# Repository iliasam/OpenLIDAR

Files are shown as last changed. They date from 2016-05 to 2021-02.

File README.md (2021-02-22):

# OpenLIDAR
Simple enough scanning laser rangefinder. Based on triangulation method.
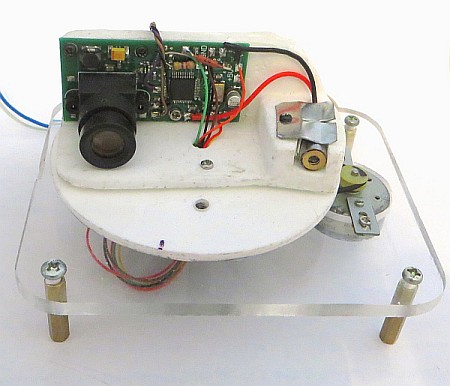
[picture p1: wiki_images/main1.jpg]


Used STM32F303 + ELIS-1024 sensor.

Article in Russian about it: https://geektimes.ru/post/275442/
  
Read wiki for more information.
  
Video - lidar installed at Roomba: https://www.youtube.com/watch?v=4vZgepiK1K4

I have another project of more simple Lidar: https://github.com/iliasam/OpenSimpleLidar  
See also my TOF Lidar project: https://github.com/iliasam/OpenTOFLidar

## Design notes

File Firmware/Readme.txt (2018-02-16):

lidar3_1 - main firmware.

lidar3_image - testing firmware, send image from image sensor to the PC.

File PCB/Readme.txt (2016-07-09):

Important - this PCB was not tested yet.
PCB size - 25x50mm.

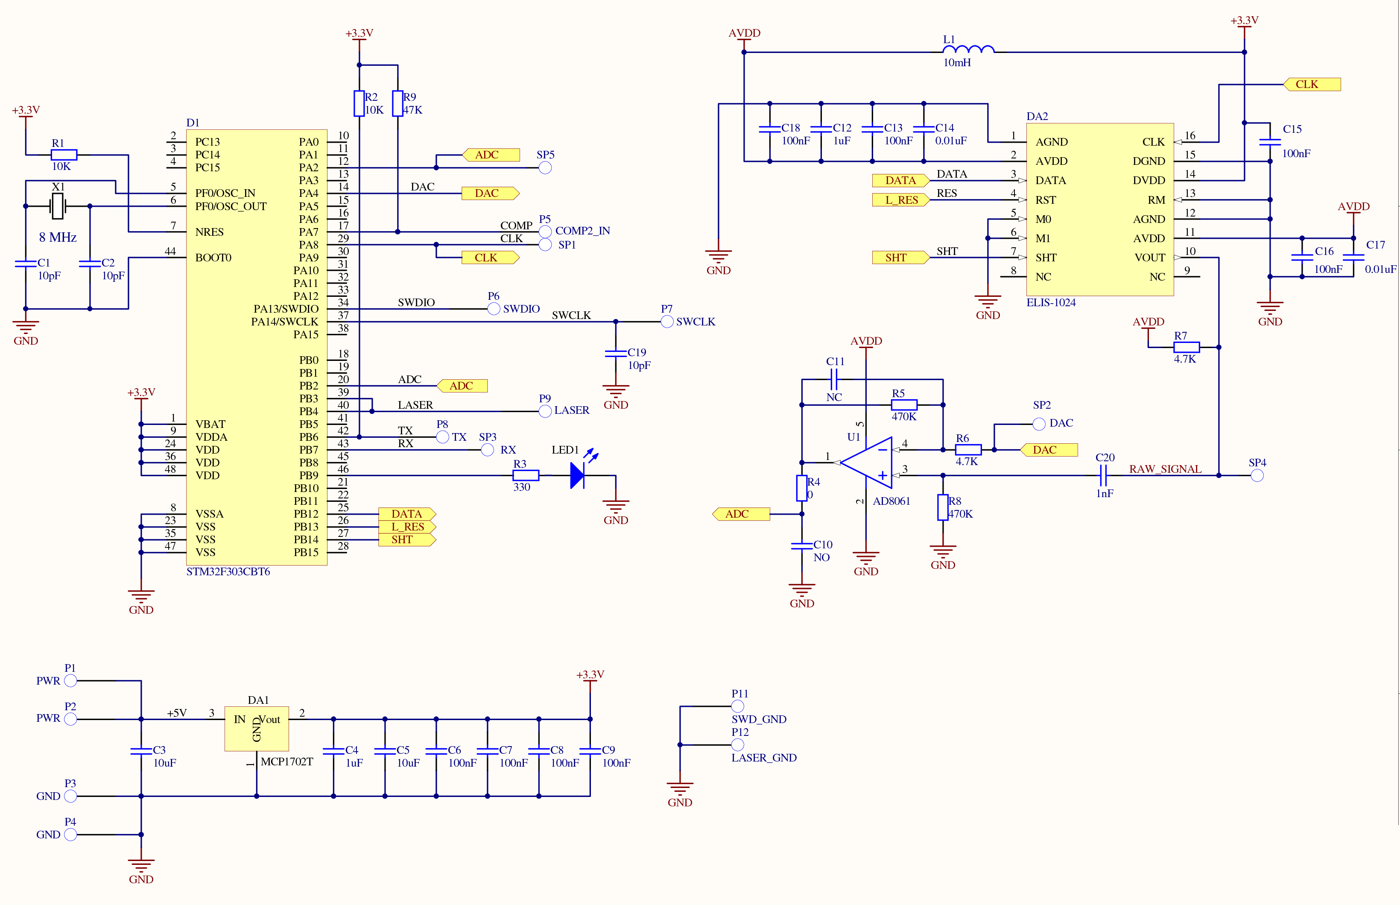
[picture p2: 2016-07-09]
Schematic/schematic_v3_2.png

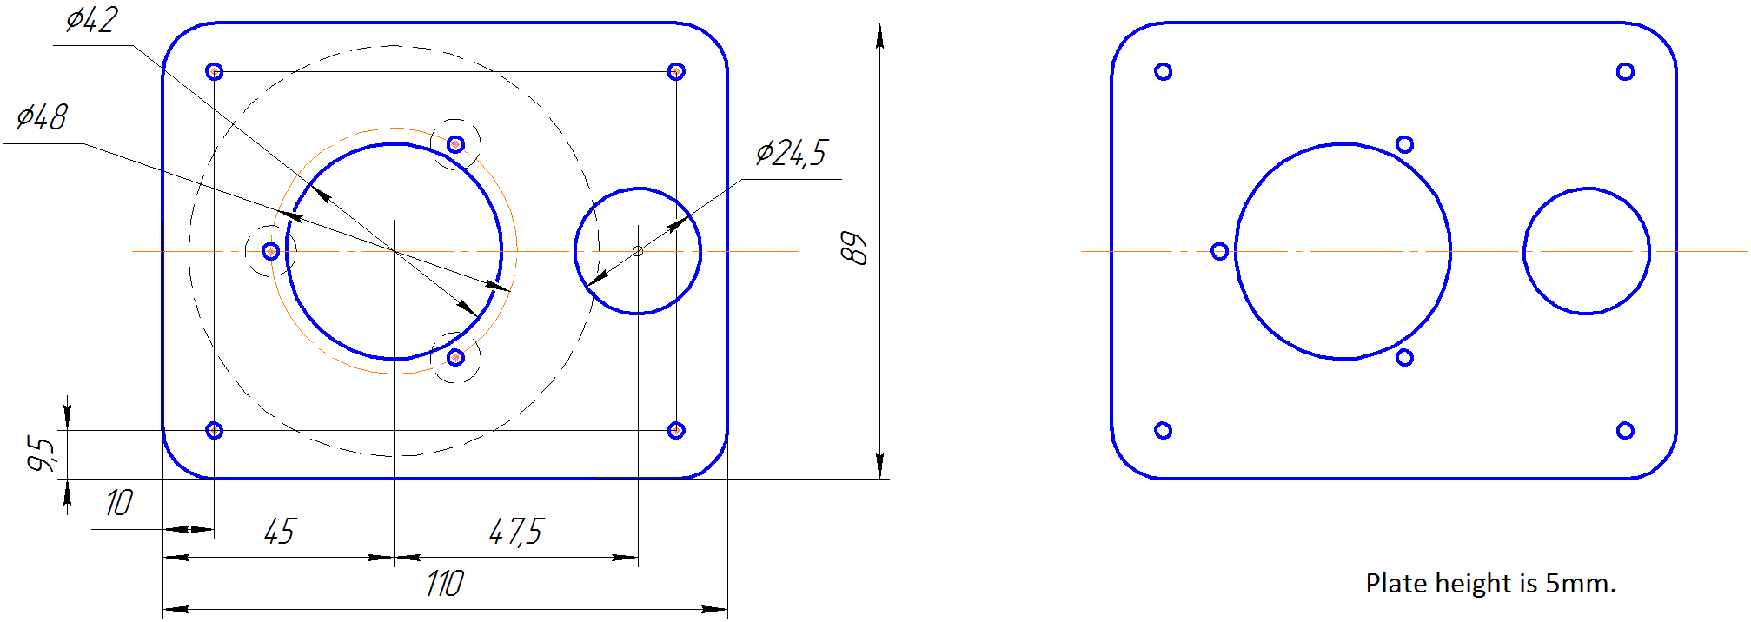
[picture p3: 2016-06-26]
3D_models/base_plate.png

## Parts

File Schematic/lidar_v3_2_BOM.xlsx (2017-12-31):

Designator | Value | Package | Comment
C1 | 10pF | 0603
C2 | 10pF | 0603
C3 | 10uF | Any
C4 | 1uF | CC0805
C5 | 10uF | Any
C6 | 100nF | 0603
C7 | 100nF | 0603
C8 | 100nF | 0603
C9 | 100nF | CC0805
C10 | NO | 0805 | Do not install
C11 | NO | 0805 | Do not install
C12 | 1uF | 0603
C13 | 100nF | 0603
C14 | 0.01uF | 0603
C15 | 100nF | 0603
C16 | 100nF | 0603
C17 | 0.01uF | 0603
C18 | 100nF | 0603
C19 | 10pF | 0603
C20 | 1nF | 0603
D1 | STM32F303CBT6 | LQFP48
DA1 | MCP1702T | MCP1702T
DA2 | ELIS-1024 | LCC16
U1 | AD8061 | SOT-23-5
L1 | 10-20 uH | Any | Inductor
LED1 | LED | 0603
R1 | 10K | 0603
R2 | 10K | 0603
R3 | 330 | 0603
R4 | NO | 0805 | Do not install
R5 | 470K | 0603
R6 | 4.7K | 0603
R7 | 4.7K | 0603
R8 | 470K | 0603
R9 | 47K | 0603
X1 | 8 MHz | SX-6 | Quarzt
P1 | PWR |  | External power
P2 | PWR |  | External power
P3 | GND |  | GND
P4 | GND |  | GND
P5 | COMP2_IN |  | To encoder
P6 | SWDIO |  | SWD
P7 | SWCLK |  | SWD
P8 | TX |  | UART TX
P9 | LASER |  | To laser module +
P11 | SWD_GND |  | SWD
P12 | LASER_GND |  | To laser module -
SP1 | CLK |  | Test point
SP2 | DAC |  | Test point
SP3 | RX |  | Test point
SP4 | RAW |  | Test point
SP5 | CLK |  | Test point

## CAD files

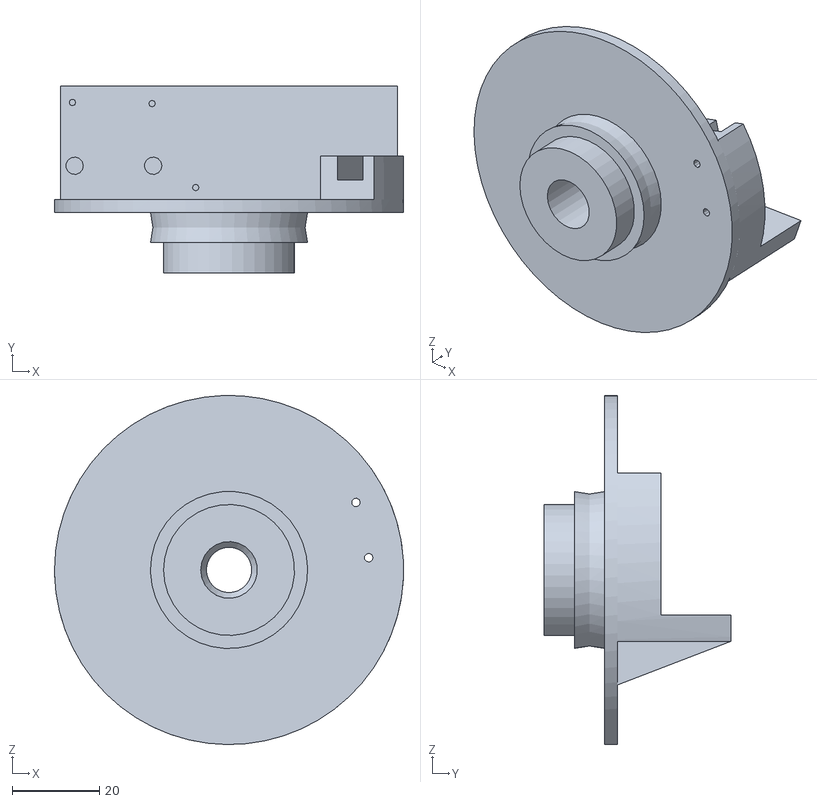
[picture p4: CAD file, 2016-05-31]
3D_models/3d_model_disk2.stl
80.0 x 42.8 x 80.0

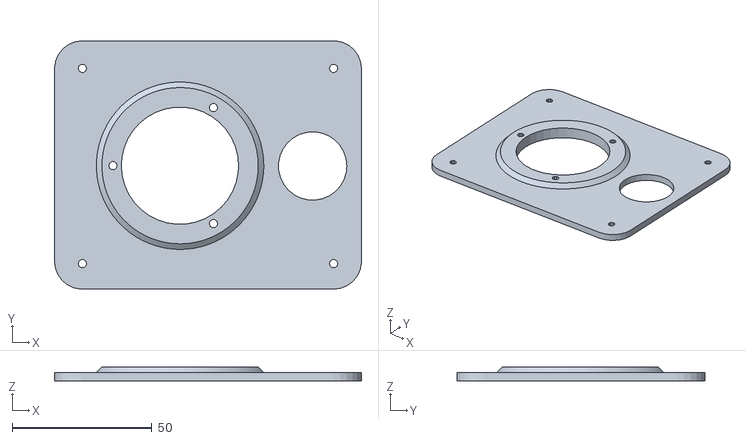
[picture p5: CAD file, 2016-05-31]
3D_models/base_plate.stl
110.0 x 89.0 x 5.00

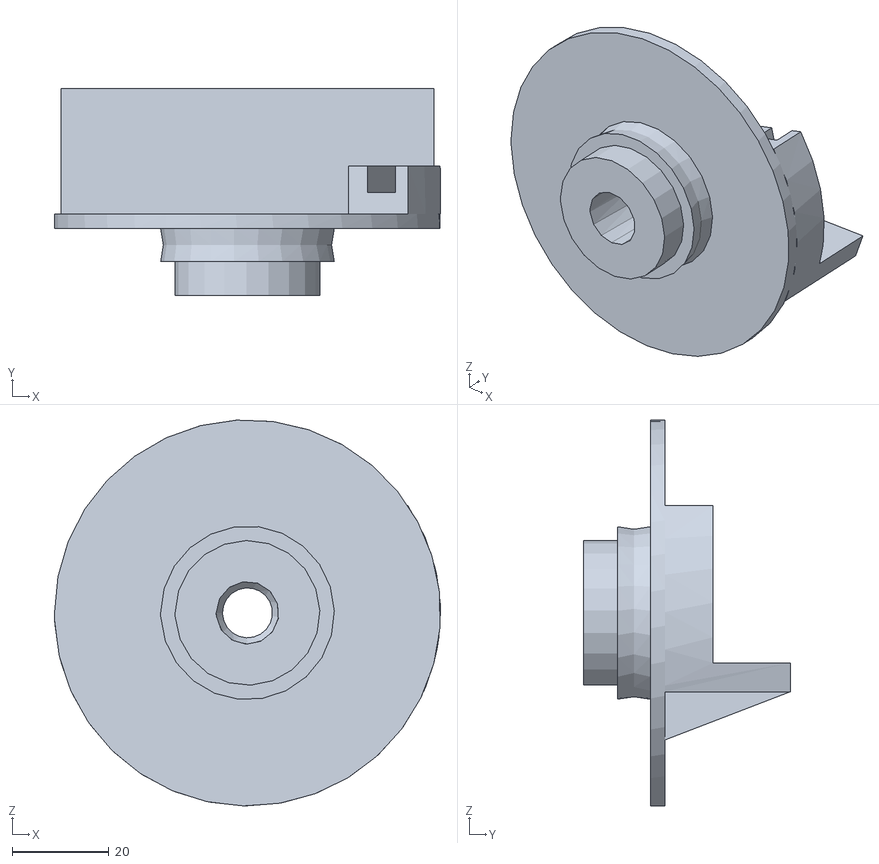
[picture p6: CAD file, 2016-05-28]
3D_models/3d_model_disk.stl
80.0 x 42.8 x 79.9

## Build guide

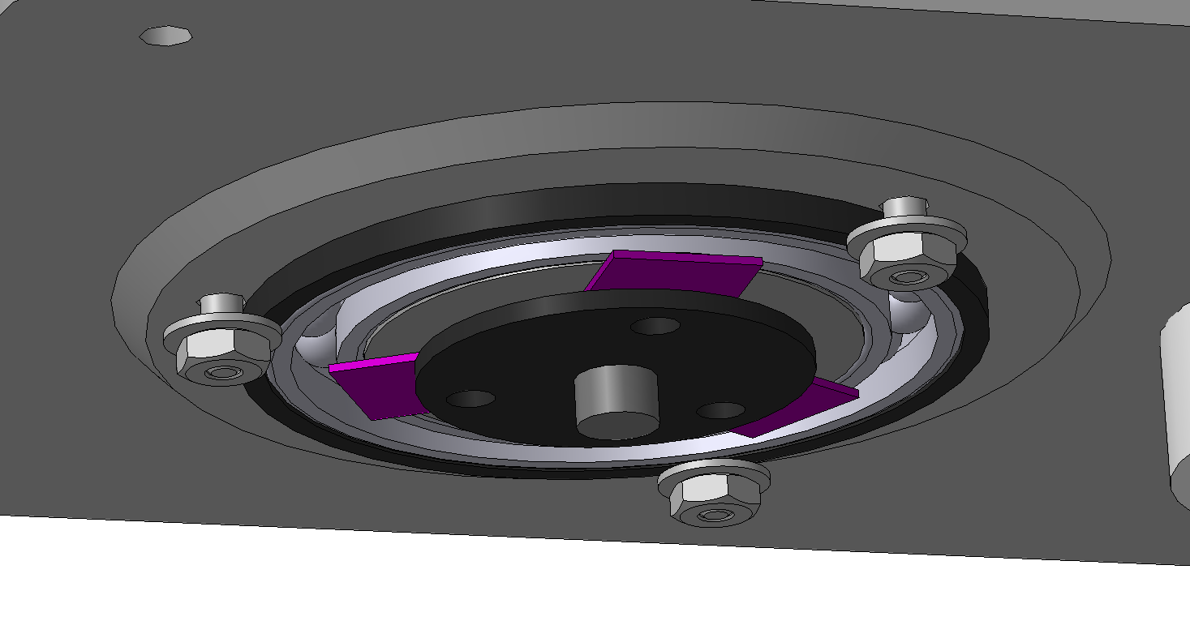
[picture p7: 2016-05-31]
3D_models/build2J.png

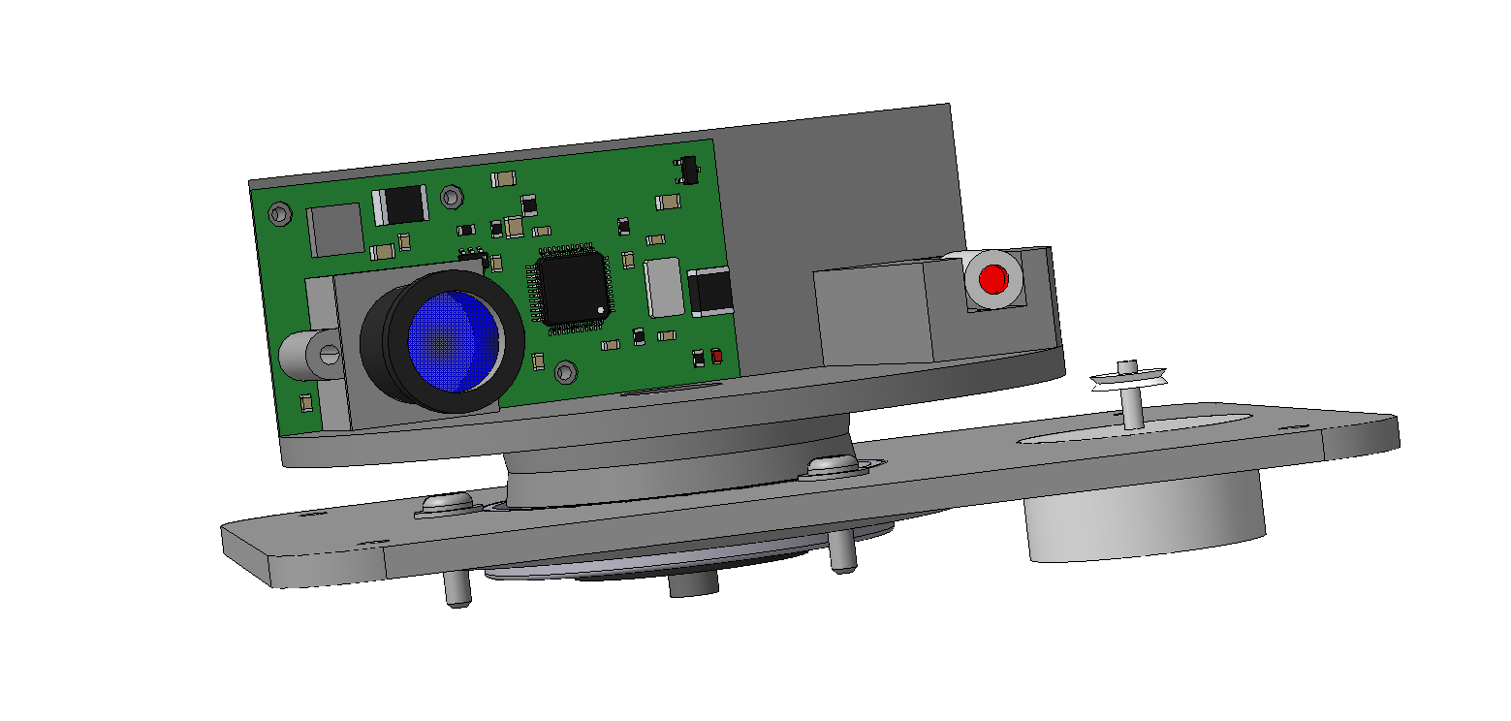
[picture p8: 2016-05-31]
3D_models/build2b.png

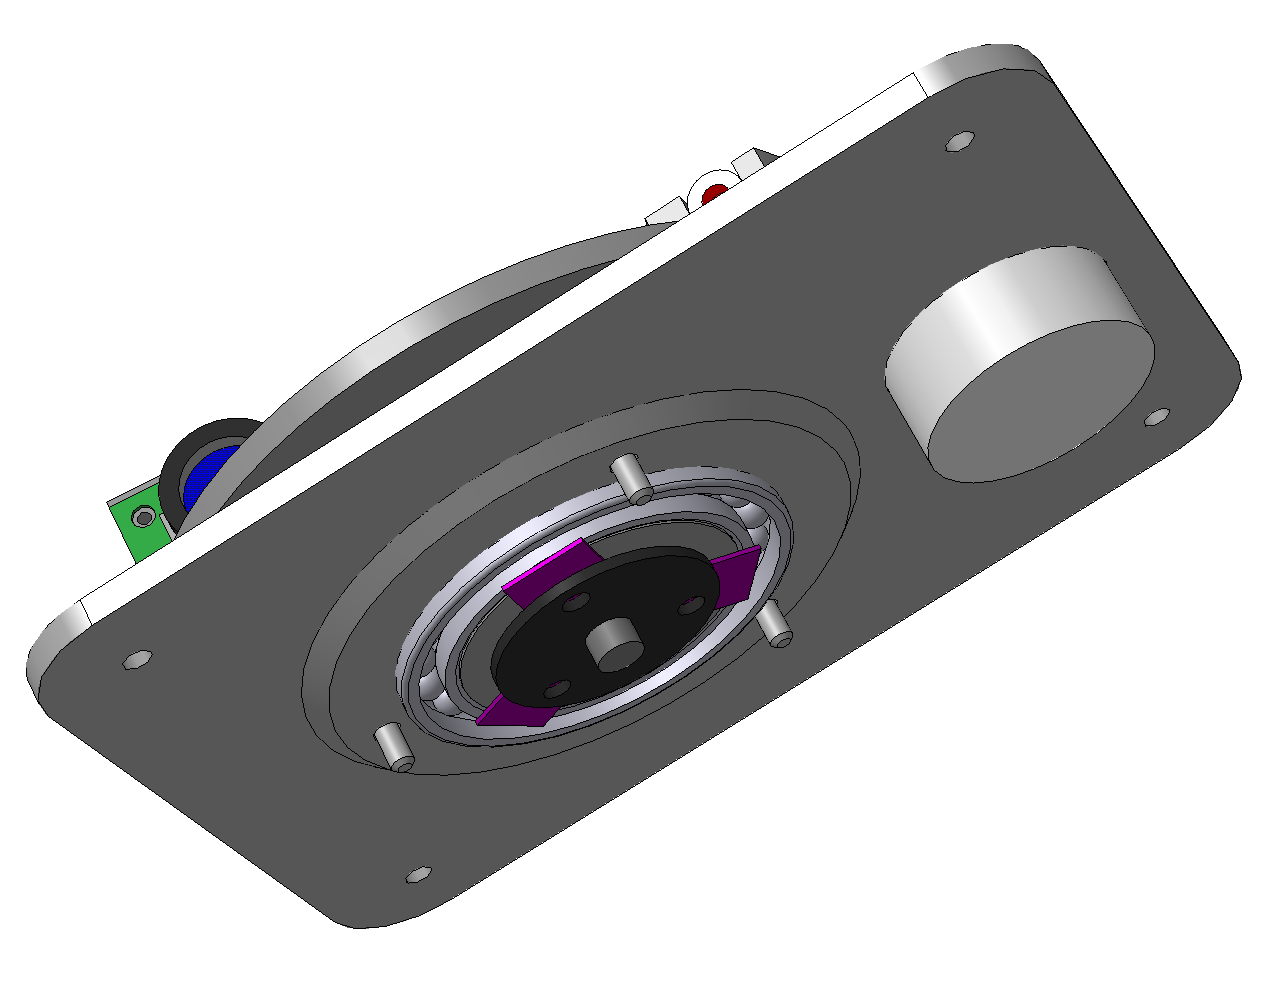
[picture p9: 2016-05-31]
3D_models/build2e.png

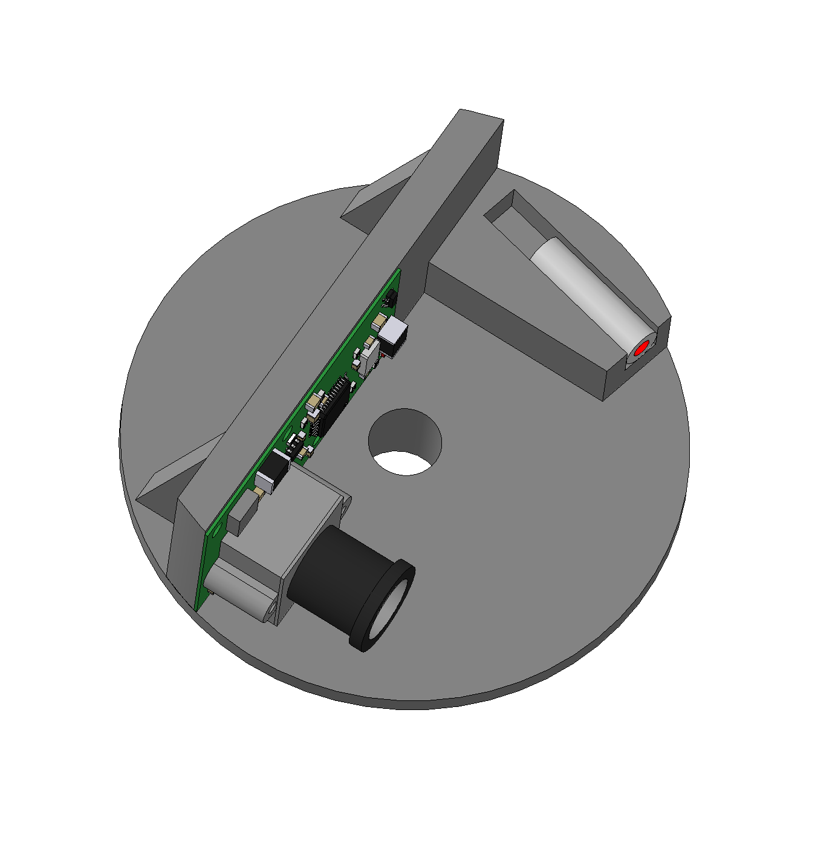
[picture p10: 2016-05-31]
3D_models/build_disk_01a.png

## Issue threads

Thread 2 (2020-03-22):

calibration

enazoe, 2020-03-22:
how to calibrate the linear ccd and laser? Do
you have any paper is about it?

iliasam, 2020-03-22:
Calibration and optic adjustments are the same as in OpenSimpleLidar: https://github.com/iliasam/OpenSimpleLidar/wiki/
Some adjustment steps are given in the article: https://habr.com/ru/post/393685/
This project is stopped, so I'm not going to add more information about it.

enazoe, 2020-03-22:
Thank you . I found this https://sites.google.com/site/todddanko/home/webcam_laser_ranger  ,and I think this method is low accuracy. So I want to find some more precison method.

Closed 2020-03-22.

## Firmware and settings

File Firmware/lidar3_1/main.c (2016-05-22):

#include "hardware.h"
#include "uart_func.h"
#include "adc_control.h"
#include "capture_control.h"
#include "speed_finder.h"

#include "stm32f30x_rcc.h"
#include "stm32f30x_tim.h"
#include "stm32f30x_comp.h"

//#define ADJ_MODE

extern volatile uint16_t line_buffer0[LINE_BUFFER_SIZE];
extern volatile uint16_t line_buffer1[LINE_BUFFER_SIZE];
extern volatile cap_status_type image_cap_status;
extern volatile uint16_t cap_number;//число захваченных точек

RCC_ClocksTypeDef RCC_Clocks;

uint16_t header[3] = {0xAABB,0xCCDD,0xEEFF};

volatile uint16_t tmp_range = 0;

int main(void)
{
	init_hardware();

    RCC_GetClocksFreq (&RCC_Clocks);
    set_led_on();

    //SysTick_Config(RCC_Clocks.HCLK_Frequency / 100);

    Delay_ms(500);
    set_led_off();
    Delay_ms(100);

    refresh_sync_timer(40);//for testing

#ifndef ADJ_MODE
    while(1)
    {
    	scan_capture_handler();
    }
#endif

#ifdef ADJ_MODE
    TIM_Cmd(TIM3, DISABLE);
    COMP_Cmd(COMP_Selection_COMP2, DISABLE);
    cap_number = 0;
    while(1)
    {
    	scan_capture_handler();
    	if (cap_number == 359)
    	{
    		Delay_ms(30);
    		stop_capture();
    		start_send_result();
    	}
    }
#endif




    while(1)
    {
    	//start_send_result();
    	//uart_send_array(&line_buffer1, LINE_BUFFER_SIZE);
    	//Delay_ms(166);

    	set_adc_buf();
    	start_1deg_capture();
    	while (image_cap_status != CAPTURE_DONE){}
    	DWT_Delay(50);
    	//Delay_ms(1);
    	//capture_dma_stop();
    	//uart_send_array(&header[0], 3);
    	//uart_send_array(&line_buffer1[0], LINE_BUFFER_SIZE);
    	//tmp_range = centroid_finder(&line_buffer1[0]);
    	//Delay_ms(35);
    	//toggle_led();
    }
}

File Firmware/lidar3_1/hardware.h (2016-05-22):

#ifndef _HARDWARE_H
#define _HARDWARE_H

#include <stdint.h>

#define LED_GPIO GPIOB
#define LED_PIN  GPIO_Pin_9

#define CLK_GPIO GPIOA
#define CLK_PIN  GPIO_Pin_8

#define ADC1_GPIO GPIOA
#define ADC2_GPIO GPIOB
#define ADC1_PIN  GPIO_Pin_2
#define ADC2_PIN  GPIO_Pin_2

#define DAC1_GPIO GPIOA
#define DAC1_PIN  GPIO_Pin_4

#define SENSOR_GPIO GPIOB
#define DATA_PIN  GPIO_Pin_12
#define RES_PIN   GPIO_Pin_13
#define SHT_PIN   GPIO_Pin_14

#define LASER_GPIO 	 GPIOB
#define LASER_PIN1   GPIO_Pin_3
#define LASER_PIN2   GPIO_Pin_4

#define UART1_GPIO 	   GPIOB
#define UART1_TX_PIN   GPIO_Pin_6
#define UART1_TX_AFIO  GPIO_PinSource6

#define ENCODER_GPIO GPIOA
#define ENCODER_PIN  GPIO_Pin_7

void init_hardware(void);

void init_gpio(void);
void init_clock(void);
void init_dac(void);
void init_uart(void);
void init_uart_DMA(void);

inline void start_exposure(void);
inline void stop_exposure(void);
void do_capture(void);

void set_laser_on(void);
void set_laser_off(void);

void init_comparator(void);


void set_led_on(void);
void set_led_off(void);
void toggle_led(void);

void Delay_ms(uint32_t ms);

void DWT_Init(void);
uint32_t DWT_Get(void);
void DWT_Delay(uint32_t us);
void init_comparator(void);


#endif

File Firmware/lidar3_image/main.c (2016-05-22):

#include "hardware.h"
#include "uart_func.h"
#include "adc_control.h"
#include "stm32f30x_rcc.h"
#include "stm32f30x_tim.h"

extern volatile uint16_t line_buffer[LINE_BUFFER_SIZE];
RCC_ClocksTypeDef RCC_Clocks;

uint16_t header[3] = {0xAABB,0xCCDD,0xEEFF};

int main(void)
{
	init_hardware();

    RCC_GetClocksFreq (&RCC_Clocks);

    start_clk_timer();
    //set_led_on();

    //SysTick_Config(RCC_Clocks.HCLK_Frequency / 100);

    Delay_ms(500);
    while(1)
    {
    	do_capture();
    	capture_dma_start();
    	start_clk_timer();
    	Delay_ms(1);
    	uart_send_array(&header[0], 3);
    	uart_send_array(&line_buffer, LINE_BUFFER_SIZE);
    	//Delay_ms(35);
    	//toggle_led();
    }
}

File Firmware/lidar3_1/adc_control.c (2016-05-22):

#include "stm32f30x.h"
#include "adc_control.h"
#include "hardware.h"
#include "stm32f30x_gpio.h"
#include "stm32f30x_rcc.h"
#include "stm32f30x_tim.h"
#include "stm32f30x_adc.h"
#include "stm32f30x_dma.h"
#include "stm32f30x_misc.h"

//#define ADC_TIMER_PERIOD 7   //72M/12 = 6mhz
//#define ADC_SAMPLING_DELAY 1 //(+1.5+1)+1

#define ADC_TIMER_PERIOD 11  //72M/12 = 6mhz
#define ADC_SAMPLING_DELAY 3//(+1.5+1)+5

volatile uint16_t line_buffer0[LINE_BUFFER_SIZE];
volatile uint16_t line_buffer1[LINE_BUFFER_SIZE];
volatile uint16_t* data_adc_p;//указатель на данные с лазером

volatile cap_status_type image_cap_status = NO_CAPTURE;

extern volatile uint16_t cap_number;//число захваченных точек


void DMA1_Channel1_IRQHandler(void)
{
  TIM1->CR1 &= (uint16_t)~TIM_CR1_CEN;//stop timer
  TIM_ForcedOC1Config(TIM1, TIM_ForcedAction_InActive);
  stop_exposure();//long exposure

  if(DMA_GetITStatus(DMA1_IT_TC1))
  {
    DMA_ClearITPendingBit(DMA1_IT_TC1);
    DMA_ITConfig(DMA1_Channel1, DMA_IT_TC, DISABLE);
    DMA_Cmd(DMA1_Channel1, DISABLE);

    image_cap_status = CAPTURE_DONE;

    //SENSOR_GPIO->BSRR = (RES_PIN);//set bit
    //stop_exposure();
  }
}

//переключает буферы захавта ацп
//вызывается из обработчика прерывания TIM16 - перед началом новгого захвата
void set_adc_buf(void)
{
	if ((cap_number & 1) == 1) //нечетные изображения в 0 буфер
	{
		data_adc_p = &line_buffer0[0];
	}
	else //четные изображения в 1 буфер
	{
		data_adc_p = &line_buffer1[0];
	}
}


//configure DMA
void capture_dma_start(void)
{
	DMA_Cmd(DMA1_Channel1, DISABLE);
	DMA_ClearITPendingBit(DMA1_IT_TC1);
	DMA1_Channel1->CNDTR = LINE_BUFFER_SIZE/2;//two adc give one 32-bit "sample"
	DMA1_Channel1->CMAR = (uint32_t)data_adc_p;
	DMA_ITConfig(DMA1_Channel1, DMA_IT_TC, ENABLE);//по прерыванию останавливается таймер 1
	ADC_ClearFlag(ADC1, ADC_FLAG_EOC|ADC_FLAG_OVR);
	ADC_ClearFlag(ADC2, ADC_FLAG_EOC|ADC_FLAG_OVR);
	DMA_Cmd(DMA1_Channel1, ENABLE);
}

void capture_dma_stop(void)
{
	TIM_Cmd(TIM1,DISABLE);
	TIM_ForcedOC1Config(TIM1, TIM_ForcedAction_InActive);
	DMA_Cmd(DMA1_Channel1, DISABLE);
	DMA_ClearITPendingBit(DMA1_IT_TC1);
	stop_exposure();
}



//must be called before "start_clk_timer"
void create_start_pulse(void)
{
	SENSOR_GPIO->BSRR = DATA_PIN;//set
	TIM_ForcedOC1Config(TIM1, TIM_ForcedAction_Active);//clk high
	asm("nop");asm("nop");asm("nop");asm("nop");
	SENSOR_GPIO->BRR = DATA_PIN;//reset
	TIM_ForcedOC1Config(TIM1, TIM_ForcedAction_InActive);//clk low
	asm("nop");asm("nop");asm("nop");asm("nop");
}

//запускает таймер 1 - он формирует clk для линейкии и управляет ADC
void start_clk_timer(void)
{
  TIM_SetCounter(TIM1, 0);
  TIM_SelectOCxM(TIM1,TIM_Channel_1,TIM_OCMode_PWM1);//для Forced
  TIM_CCxCmd(TIM1,TIM_Channel_1,TIM_CCx_Enable);//для Forced
  TIM_Cmd(TIM1,ENABLE);
}


//формирует clk для линейки и управляет ADC
void init_timer1(void)
{
  RCC_APB2PeriphClockCmd(RCC_APB2Periph_TIM1, ENABLE);//APB2 = HCLK

  TIM_TimeBaseInitTypeDef TIM_TimeBaseStructure;
  TIM_OCInitTypeDef TIM_OCInitStructure;

  TIM_TimeBaseStructInit(&TIM_TimeBaseStructure);

  TIM_DeInit(TIM1);

  TIM_TimeBaseStructure.TIM_Prescaler = 0;
  //TIM_TimeBaseStructure.TIM_Period = 11;//72M/12 = 6mhz
  TIM_TimeBaseStructure.TIM_Period = ADC_TIMER_PERIOD;
  TIM_TimeBaseStructure.TIM_ClockDivision = TIM_CKD_DIV1;
  TIM_TimeBaseStructure.TIM_CounterMode = TIM_CounterMode_Up;
  TIM_TimeBaseInit(TIM1, &TIM_TimeBaseStructure);

  //3MHZ - adc trigger
  TIM_OCStructInit(&TIM_OCInitStructure);
  TIM_OCInitStructure.TIM_OCMode = TIM_OCMode_Toggle;
  TIM_OCInitStructure.TIM_OutputState = TIM_OutputState_Disable;
  TIM_OCInitStructure.TIM_Pulse = 1;//PWM DUTY
  TIM_OCInitStructure.TIM_OCPolarity = TIM_OCPolarity_High;
  TIM_OC2Init(TIM1,&TIM_OCInitStructure);
  //TIM_SelectOutputTrigger2(TIM1, TIM_TRGOSource_OC2Ref);//for adc

  //6MHZ - ext clk generator
  TIM_OCStructInit(&TIM_OCInitStructure);
  TIM_OCInitStructure.TIM_OCMode = TIM_OCMode_PWM1;
  TIM_OCInitStructure.TIM_OutputState = TIM_OutputState_Enable;
  TIM_OCInitStructure.TIM_Pulse = 3;
  TIM_OCInitStructure.TIM_OCPolarity = TIM_OCPolarity_High;
  TIM_OC1Init(TIM1,&TIM_OCInitStructure);

  TIM_OC1PreloadConfig(TIM1, TIM_OCPreload_Enable);
  TIM_OC2PreloadConfig(TIM1, TIM_OCPreload_Enable);

  TIM_SelectOutputTrigger(TIM1, TIM_TRGOSource_Reset);//not adc
  TIM_CCxCmd(TIM1,TIM_Channel_1,TIM_CCx_Enable);
  TIM_CCxCmd(TIM1,TIM_Channel_2,TIM_CCx_Enable);
  TIM_CtrlPWMOutputs(TIM1 , ENABLE);

  TIM_ARRPreloadConfig(TIM1,ENABLE);
}

//ADC1 & ADC2 for image capture
void adc_init(void)
{
  ADC_InitTypeDef ADC_InitStructure;
  ADC_CommonInitTypeDef ADC_CommonInitStructure;
  DMA_InitTypeDef DMA_InitStructure;
  GPIO_InitTypeDef GPIO_InitStructure;
  NVIC_InitTypeDef      NVIC_InitStructure;

  RCC_ADCCLKConfig(RCC_ADC12PLLCLK_Div1);
  RCC_AHBPeriphClockCmd(RCC_AHBPeriph_ADC12, ENABLE);
  RCC_AHBPeriphClockCmd(RCC_AHBPeriph_DMA1, ENABLE);
  RCC_AHBPeriphClockCmd(RCC_AHBPeriph_GPIOB, ENABLE);
  
  // Configure ADC Channel 12 pin as analog input
  GPIO_StructInit(&GPIO_InitStructure);
  GPIO_InitStructure.GPIO_Pin = ADC1_PIN;
  GPIO_InitStructure.GPIO_Mode = GPIO_Mode_AN;
  GPIO_InitStructure.GPIO_PuPd = GPIO_PuPd_NOPULL ;
  GPIO_Init(ADC1_GPIO, &GPIO_InitStructure);
  GPIO_InitStructure.GPIO_Pin = ADC2_PIN;
  GPIO_Init(ADC2_GPIO, &GPIO_InitStructure);

  DMA_DeInit(DMA1_Channel1);//master
  DMA_StructInit(&DMA_InitStructure);
  DMA_InitStructure.DMA_PeripheralBaseAddr = (uint32_t)&ADC1_2->CDR;
  DMA_InitStructure.DMA_MemoryBaseAddr = (uint32_t)&line_buffer0[0];
  DMA_InitStructure.DMA_DIR = DMA_DIR_PeripheralSRC;
  DMA_InitStructure.DMA_BufferSize = LINE_BUFFER_SIZE/2;
  DMA_InitStructure.DMA_PeripheralInc = DMA_PeripheralInc_Disable;
  DMA_InitStructure.DMA_MemoryInc = DMA_MemoryInc_Enable;
  DMA_InitStructure.DMA_PeripheralDataSize = DMA_PeripheralDataSize_Word;
  DMA_InitStructure.DMA_MemoryDataSize = DMA_MemoryDataSize_Word;
  DMA_InitStructure.DMA_Mode = DMA_Mode_Normal;
  DMA_InitStructure.DMA_Priority = DMA_Priority_VeryHigh;
  DMA_InitStructure.DMA_M2M = DMA_M2M_Disable;
  DMA_Init(DMA1_Channel1, &DMA_InitStructure);
  
  DMA_ClearITPendingBit(DMA1_IT_TC1);

  DMA_Cmd(DMA1_Channel1, ENABLE);

  NVIC_InitStructure.NVIC_IRQChannel = DMA1_Channel1_IRQn;
  NVIC_InitStructure.NVIC_IRQChannelPreemptionPriority = 1;//highest
  NVIC_InitStructure.NVIC_IRQChannelSubPriority = 0;
  NVIC_InitStructure.NVIC_IRQChannelCmd = ENABLE;
  NVIC_Init(&NVIC_InitStructure);

  DMA_ITConfig(DMA1_Channel1, DMA_IT_TC, ENABLE);

  ADC_DeInit(ADC1);
  ADC_DeInit(ADC2);

  ADC_VoltageRegulatorCmd(ADC1, ENABLE);
  ADC_VoltageRegulatorCmd(ADC2, ENABLE);
  DWT_Delay(20);
  ADC_SelectCalibrationMode(ADC1, ADC_CalibrationMode_Single);
  ADC_StartCalibration(ADC1);
  while(ADC_GetCalibrationStatus(ADC1) != RESET);

  ADC_SelectCalibrationMode(ADC2, ADC_CalibrationMode_Single);
  ADC_StartCalibration(ADC2);
  while(ADC_GetCalibrationStatus(ADC2) != RESET);
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

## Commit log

2016-05-28 Disk 3d model added
    [3d_model_disk.stl]
2016-05-30 Files added
    [3d_model_disk2.stl]
2016-05-31 3d models and renders added
    [3d_model_disk2.stl, base_plate.stl]
2016-07-09 PCB files added
    [PCB1.GBL, PCB1.GBO, PCB1.GBS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]
2016-07-09 Schematic update
2017-12-31 PCB assemblying picture and BOM was added.
    [lidar_v3_2_BOM.xlsx]
2018-02-11 Refactoring + improved compability with lidar4 (Open Simple Lidar).
